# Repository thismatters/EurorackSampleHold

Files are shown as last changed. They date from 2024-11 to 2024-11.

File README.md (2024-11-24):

# Noise / Sample Hold

This module both generates random noise (white and pink) which can be used as an audio signal directly, or slow moving random voltages appropriate to use a CV. Additionally, it can sample that random noise and hold a CV (slash V/Oct). Module has an internal clock to control sample rate, which can be overridden.

The circuit here is based on the [Yusynth Random Module](https://yusynth.net/Modular/EN/NOISE/index.html) with minor tweaks to make it more Eurorack friendly. The changes I've made are thus:
* Selected resistors appropriate for +/-12V rails,
* Added polarity protection so that a backward power header doesn't fry anything (twin series schotty diodes: BAT54SL),
* Full surface mount design.

The Yusynth page is a treasure trove of information about this circuit that I am too amateur to claim as my own; please read that outstanding page before using this circuit. The page provides many details and other implementations of this circuit that you may find suitable.

The KiCAD project here uses the library/footprints [found in my companion repo](https://github.com/thismatters/EurorackKiCAD).

## Width

13hp on an Intellijel 1U rack.

## Inputs

Jacks for:
- Signal to be sampled,
- Gate controlling when sample is taken.

Switch for selecting between noise:
- White,
- Pink,
- Slow moving random voltage.

Knob for setting internal clock for sample rate.

## Outputs

Jacks for:
- Selected noise,
- Clock,
- Held voltage.

## Adjustment

Build this module using a socket for the discrete transistor. Try several transistors until you get a good spectrum of both white and pink noise.

## Vendors

There are part numbers in the [BOM](.csv) for many of the parts (not for basic passives though) at the following vendors:

* [Mouser](https://www.mouser.com): Needs no introduction. Get your ICs from here (or [digikey](https://www.digikey.com)).
* [Tayda Electronics](https://www.taydaelectronics.com/): Good supplier for passive components; audio jacks, and potentiometers. Their audio jacks are slightly smaller than the thonkiconn from thonk.
* [Love My Switches](https://lovemyswitches.com/): Has [really good knobs](https://lovemyswitches.com/anodized-aluminum-knob-the-lo-fi-1-4-smooth-shaft-12-5mm-od/) to go on those potentiometers!
* [OSHPark](https://oshpark.com/): Fast and (relatively) cheap PCB manufacturer. The [V0 circuit](https://oshpark.com/shared_projects/IxCpIOaM) works great!

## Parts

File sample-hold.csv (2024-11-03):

# | Reference | Qty | Value | Footprint | DNP | Vendor | PartNum
1 | C1, C2, C3, C4 | 4 | 22u 50V | Capacitor_THT:CP_Radial_D5.0mm_P2.50mm
2 | C5, C6 | 2 | 47u 50V | Capacitor_THT:CP_Radial_D6.3mm_P2.50mm
3 | C7, C18 | 2 | 100n | Capacitor_SMD:C_0805_2012Metric
4 | C8, C13, C21 | 3 | 10u 35V | Capacitor_THT:CP_Radial_D5.0mm_P2.50mm
5 | C9, C14 | 2 | 10p | Capacitor_SMD:C_0805_2012Metric
6 | C10 | 1 | 47n box | Capacitor_THT:C_Rect_L7.2mm_W2.5mm_P5.00mm_FKS2_FKP2_MKS2_MKP2
7 | C11 | 1 | 1n box | Capacitor_THT:C_Rect_L7.2mm_W2.5mm_P5.00mm_FKS2_FKP2_MKS2_MKP2
8 | C12 | 1 | 3.3n box | Capacitor_THT:C_Rect_L7.2mm_W2.5mm_P5.00mm_FKS2_FKP2_MKS2_MKP2
9 | C15, C16 | 2 | 1u box | Capacitor_THT:C_Rect_L7.2mm_W5.5mm_P5.00mm_FKS2_FKP2_MKS2_MKP2
10 | C17 | 1 | 150n box | Capacitor_THT:C_Rect_L7.2mm_W3.5mm_P5.00mm_FKS2_FKP2_MKS2_MKP2
11 | C19 | 1 | 1n | Capacitor_SMD:C_0805_2012Metric
12 | C20 | 1 | 100n box | Capacitor_THT:C_Rect_L7.2mm_W2.5mm_P5.00mm_FKS2_FKP2_MKS2_MKP2
13 | D1, D2 | 2 | BAT54S | Package_TO_SOT_SMD:SOT-23 |  | Mouser | 863-BAT54SLT1G
14 | D3, D4, D5 | 3 | 1N4148 | Diode_SMD:D_SOD-323_HandSoldering
15 | J1 | 1 | Conn_02x05_Odd_Even | Eurorack:PinHeader_2x05_P2.54mm_Vertical |  | Tayda | A-2939
16 | J2, J3, J4, J5, J6 | 5 | AudioJack2_SwitchT | Eurorack:AudioJack2_Tayda_A-2566 |  | Tayda | A-2566
17 | J7, J9, J11 | 3 | Conn_01x03_Pin | Connector_PinHeader_2.54mm:PinHeader_1x03_P2.54mm_Vertical
18 | J8, J10, J12 | 3 | Conn_01x03_Socket | Connector_PinSocket_2.54mm:PinSocket_1x03_P2.54mm_Vertical
19 | Q1 | 1 | BC547C | Package_TO_SOT_THT:TO-92_Inline_Wide |  | Mouser | 637-BC547C
20 | Q2 | 1 | BCM847 | Package_SO:TSOP-6_1.65x3.05mm_P0.95mm |  | Mouser | 771-BCM847DS135
21 | Q3 | 1 | MMBFJ111 | Package_TO_SOT_SMD:SOT-23 |  | Mouser | 863-MMBF4393LT1G
22 | R1, R2, R3, R4 | 4 | 10 | Resistor_SMD:R_0805_2012Metric
23 | R5 | 1 | 47K | Resistor_SMD:R_0805_2012Metric
24 | R6 | 1 | 150K | Resistor_SMD:R_0805_2012Metric
25 | R7, R22, R28 | 3 | 10K | Resistor_SMD:R_0805_2012Metric
26 | R8 | 1 | 22 | Resistor_SMD:R_0805_2012Metric
27 | R9, R20, R21, R43 | 4 | 33K | Resistor_SMD:R_0805_2012Metric
28 | R10, R18 | 2 | 470K | Resistor_SMD:R_0805_2012Metric
29 | R11, R19, R24, R25, R32, R36 | 6 | 1K | Resistor_SMD:R_0805_2012Metric
30 | R12 | 1 | 82K | Resistor_SMD:R_0805_2012Metric
31 | R13, R26, R27, R29, R30, R34, R37, R38, R39, R40 | 10 | 100K | Resistor_SMD:R_0805_2012Metric
32 | R14 | 1 | 18K | Resistor_SMD:R_0805_2012Metric
33 | R15 | 1 | 390K | Resistor_SMD:R_0805_2012Metric
34 | R16 | 1 | 1M | Resistor_SMD:R_0805_2012Metric
35 | R17 | 1 | 8.2K | Resistor_SMD:R_0805_2012Metric
36 | R23 | 1 | 220K | Resistor_SMD:R_0805_2012Metric
37 | R31 | 1 | 2.2M | Resistor_SMD:R_0805_2012Metric
38 | R33 | 1 | 2.2K | Resistor_SMD:R_0805_2012Metric
39 | R35 | 1 | 120K | Resistor_SMD:R_0805_2012Metric
40 | R41 | 1 | 3.9K | Resistor_SMD:R_0805_2012Metric
41 | R42 | 1 | 24K | Resistor_SMD:R_0805_2012Metric
42 | RV1 | 1 | C500K | Eurorack:Potentiometer_RV16AF-41-15R1 |  | Tayda | A-3940
43 | SW1 | 1 | ON-ON-ON | Eurorack:Switch_DPDT_Tayda_A-5752 |  | Tayda | A-6677
44 | U1, U2 | 2 | TL074 | Package_SO:SOIC-14_3.9x8.7mm_P1.27mm |  | Mouser | 595-TL074CDR

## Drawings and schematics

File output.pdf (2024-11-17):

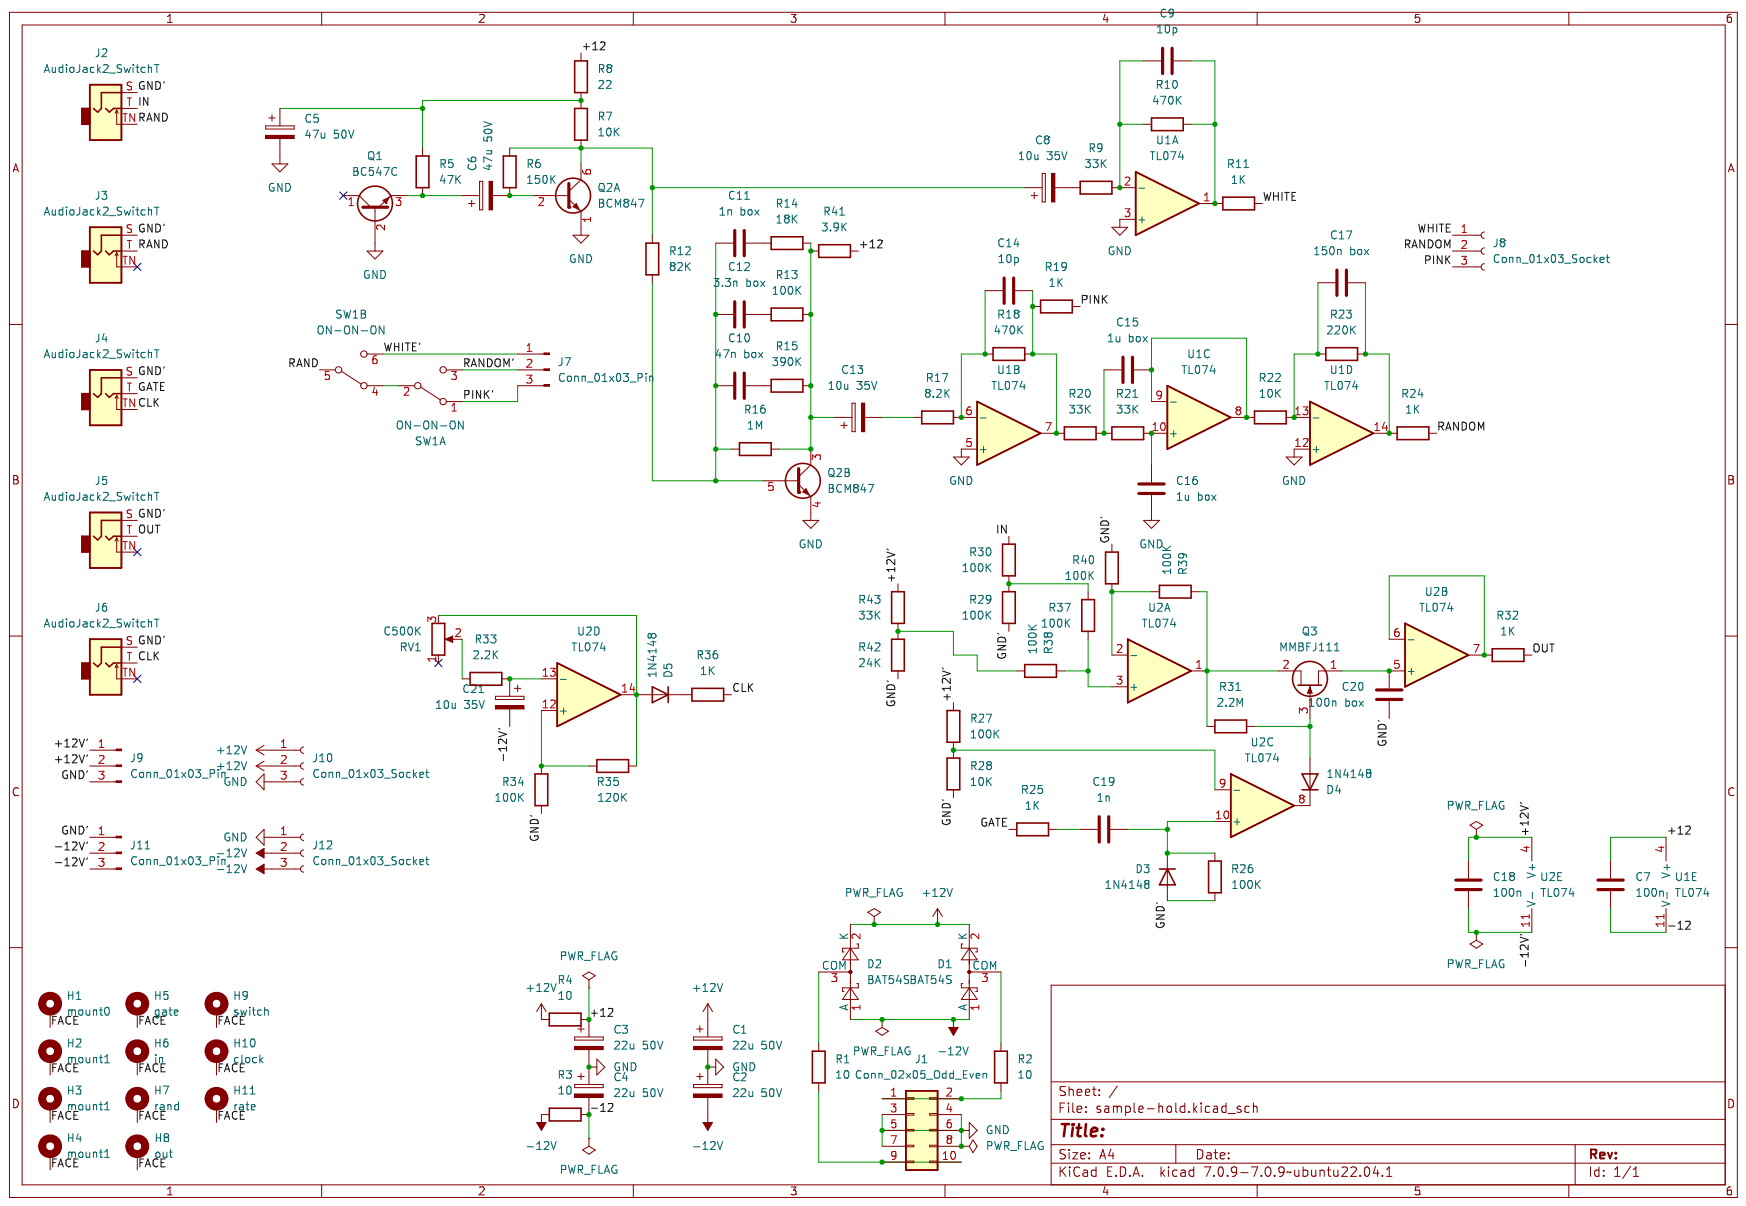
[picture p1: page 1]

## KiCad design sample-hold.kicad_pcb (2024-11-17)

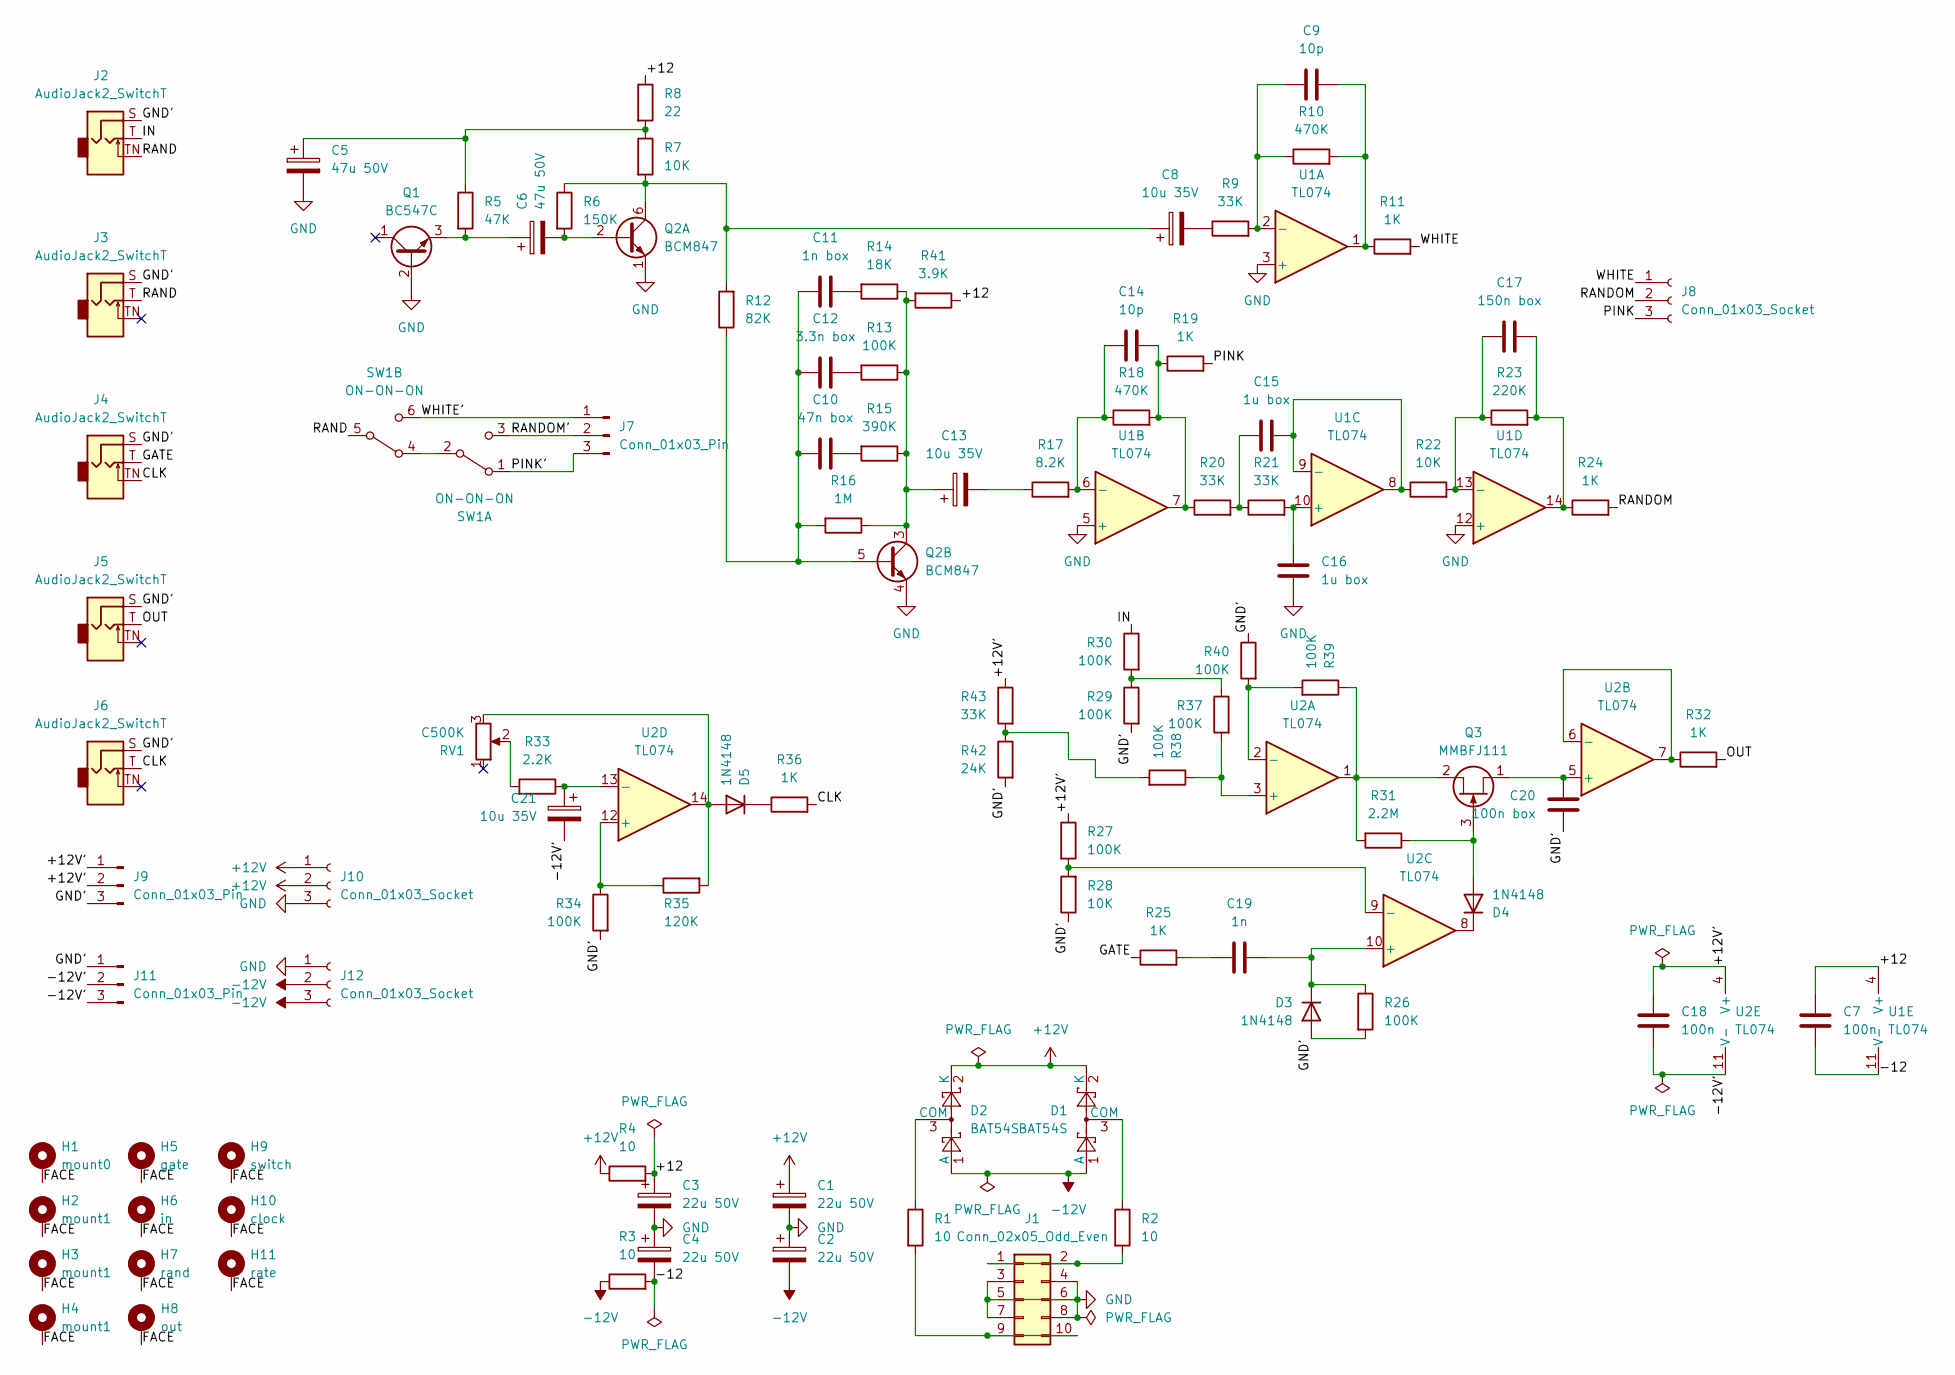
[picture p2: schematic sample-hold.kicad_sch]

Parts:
C1, C2, C3, C4: 22u 50V; CP_Radial_D5.0mm_P2.50mm
C5, C6: 47u 50V; CP_Radial_D6.3mm_P2.50mm
C7, C18: 100n; C_0805_2012Metric
C8, C13, C21: 10u 35V; CP_Radial_D5.0mm_P2.50mm
C9, C14: 10p; C_0805_2012Metric
C10: 47n box; C_Rect_L7.2mm_W2.5mm_P5.00mm_FKS2_FKP2_MKS2_MKP2
C11: 1n box; C_Rect_L7.2mm_W2.5mm_P5.00mm_FKS2_FKP2_MKS2_MKP2
C12: 3.3n box; C_Rect_L7.2mm_W2.5mm_P5.00mm_FKS2_FKP2_MKS2_MKP2
C15, C16: 1u box; C_Rect_L7.2mm_W5.5mm_P5.00mm_FKS2_FKP2_MKS2_MKP2
C17: 150n box; C_Rect_L7.2mm_W3.5mm_P5.00mm_FKS2_FKP2_MKS2_MKP2
C19: 1n; C_0805_2012Metric
C20: 100n box; C_Rect_L7.2mm_W2.5mm_P5.00mm_FKS2_FKP2_MKS2_MKP2
D1, D2: BAT54S; SOT-23; PartNum 863-BAT54SLT1G
D3, D4, D5: 1N4148; D_SOD-323_HandSoldering
H1: mount0; Mech-MountingHole
H2, H3, H4: mount1; Mech-MountingHole
H5: gate; Mech-AudioJack-Hole-Input-Gate
H6: in; Mech-AudioJack-Hole-Input-Voct
H7: rand; Mech-AudioJack-Hole-Output-Voct
H8: out; Mech-AudioJack-Hole-Output-Voct
H9: switch; Mech-2M_Switch-Hole
H10: clock; Mech-AudioJack-Hole-Output-Clock
H11: rate; Mech-Potentiometer-Hole_level_90deg
J1: Conn_02x05_Odd_Even; PinHeader_2x05_P2.54mm_Vertical; PartNum A-2939
J2, J3, J4, J5, J6: AudioJack2_SwitchT; AudioJack2_Tayda_A-2566; PartNum A-2566
J7, J9, J11: Conn_01x03_Pin; PinHeader_1x03_P2.54mm_Vertical
J8, J10, J12: Conn_01x03_Socket; PinSocket_1x03_P2.54mm_Vertical
Q1: BC547C; TO-92_Inline_Wide; PartNum 637-BC547C
Q2: BCM847; TSOP-6_1.65x3.05mm_P0.95mm; PartNum 771-BCM847DS135
Q3: MMBFJ111; SOT-23; PartNum 863-MMBF4393LT1G
R1, R2, R3, R4: 10; R_0805_2012Metric
R5: 47K; R_0805_2012Metric
R6: 150K; R_0805_2012Metric
R7, R22, R28: 10K; R_0805_2012Metric
R8: 22; R_0805_2012Metric
R9, R20, R21, R43: 33K; R_0805_2012Metric
R10, R18: 470K; R_0805_2012Metric
R11, R19, R24, R25, R32, R36: 1K; R_0805_2012Metric
R12: 82K; R_0805_2012Metric
R13, R26, R27, R29, R30, R34, R37, R38, R39, R40: 100K; R_0805_2012Metric
R14: 18K; R_0805_2012Metric
R15: 390K; R_0805_2012Metric
R16: 1M; R_0805_2012Metric
R17: 8.2K; R_0805_2012Metric
R23: 220K; R_0805_2012Metric
R31: 2.2M; R_0805_2012Metric
R33: 2.2K; R_0805_2012Metric
R35: 120K; R_0805_2012Metric
R41: 3.9K; R_0805_2012Metric
R42: 24K; R_0805_2012Metric
RV1: C500K; Potentiometer_RV16AF-41-15R1; PartNum A-3940
SW1: ON-ON-ON; Switch_DPDT_Tayda_A-5752; PartNum A-6677
U1, U2: TL074; SOIC-14_3.9x8.7mm_P1.27mm; PartNum 595-TL074CDR

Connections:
+12V: C1.1, D1.2 (K), D2.2 (K), J10.1, J10.2, R4.1
-12V: C2.2, D1.1 (A), D2.1 (A), J12.2, J12.3, R3.1
/+12: C3.1, C7.1, R4.2, R8.1, R41.1, U1.4 (V+)
/+12V': C18.1, J9.1, J9.2, R27.1, R43.1, U2.4 (V+)
/-12: C4.2, C7.2, R3.2, U1.11 (V-)
/-12V': C18.2, C21.2, J11.2, J11.3, U2.11 (V-)
/CLK: J4.TN, J6.T, R36.2
/FACE: H1.1, H2.1, H3.1, H4.1, H5.1, H6.1, H7.1, H8.1, H9.1, H10.1, H11.1
/GATE: J4.T, R25.1
/GND': C20.2, D3.2 (A), J2.S, J3.S, J4.S, J5.S, J6.S, J9.3, J11.1, R26.2, R28.1, R29.2, R34.2, R40.1, R42.2
/IN: J2.T, R30.1
/OUT: J5.T, R32.2
/PINK: J8.3, R19.2
/PINK': J7.3, SW1.1 (A)
/RAND: J2.TN, J3.T, SW1.5 (B)
/RANDOM: J8.2, R24.2
/RANDOM': J7.2, SW1.3 (C)
/WHITE: J8.1, R11.2
/WHITE': J7.1, SW1.6 (C)
GND: C1.2, C2.1, C3.2, C4.1, C5.2, C16.1, J1.3, J1.4, J1.5, J1.6, J1.7, J1.8, J10.3, J12.1, Q1.2 (B), Q2.1 (E1), Q2.4 (E2), U1.3 (+), U1.5 (+), U1.12 (+)
unnamed: C5.1, R5.1, R7.1, R8.2
unnamed: C8.2, R9.1
unnamed: C9.2, R10.2, R11.1, U1.1
unnamed: C10.2, R15.2
unnamed: C11.2, R14.2
unnamed: C12.2, R13.2
unnamed: C13.2, R17.1
unnamed: C14.2, R18.2, R19.1, R20.1, U1.7
unnamed: C15.1, R20.2, R21.1
unnamed: C17.2, R23.2, R24.1, U1.14
unnamed: C19.1, R25.2
unnamed: D1.3 (COM), R2.1
unnamed: D2.3 (COM), R1.1
unnamed: C19.2, D3.1 (K), R26.1, U2.10 (+)
unnamed: D4.2 (A), Q3.3 (G), R31.1
unnamed: D4.1 (K), U2.8
unnamed: D5.2 (A), R35.2, RV1.3, U2.14
unnamed: D5.1 (K), R36.1
unnamed: J1.1, J1.2, R2.2
unnamed: J1.9, J1.10, R1.2
unnamed: C6.1, Q1.3 (E), R5.2
unnamed: C6.2, Q2.2 (B1), R6.2
unnamed: C8.1, Q2.6 (C1), R6.1, R7.2, R12.2
unnamed: C10.1, C11.1, C12.1, Q2.5 (B2), R12.1, R16.2
unnamed: C13.1, Q2.3 (C2), R13.1, R14.1, R15.1, R16.1, R41.2
unnamed: C20.1, Q3.1 (D), U2.5 (+)
unnamed: Q3.2 (S), R31.2, R39.1, U2.1
unnamed: R29.1, R30.2, R37.1
unnamed: R33.2, RV1.2
unnamed: R38.2, R42.1, R43.2
unnamed: SW1.2 (B), SW1.4 (A)
unnamed: C9.1, R9.2, R10.1, U1.2 (-)
unnamed: C14.1, R17.2, R18.1, U1.6 (-)
unnamed: C16.2, R21.2, U1.10 (+)
unnamed: C15.2, R22.1, U1.8, U1.9 (-)
unnamed: C17.1, R22.2, R23.1, U1.13 (-)
unnamed: R37.2, R38.1, U2.3 (+)
unnamed: R39.2, R40.2, U2.2 (-)
unnamed: R32.1, U2.6 (-), U2.7
unnamed: R27.2, R28.2, U2.9 (-)
unnamed: R34.1, R35.1, U2.12 (+)
unnamed: C21.1, R33.1, U2.13 (-)

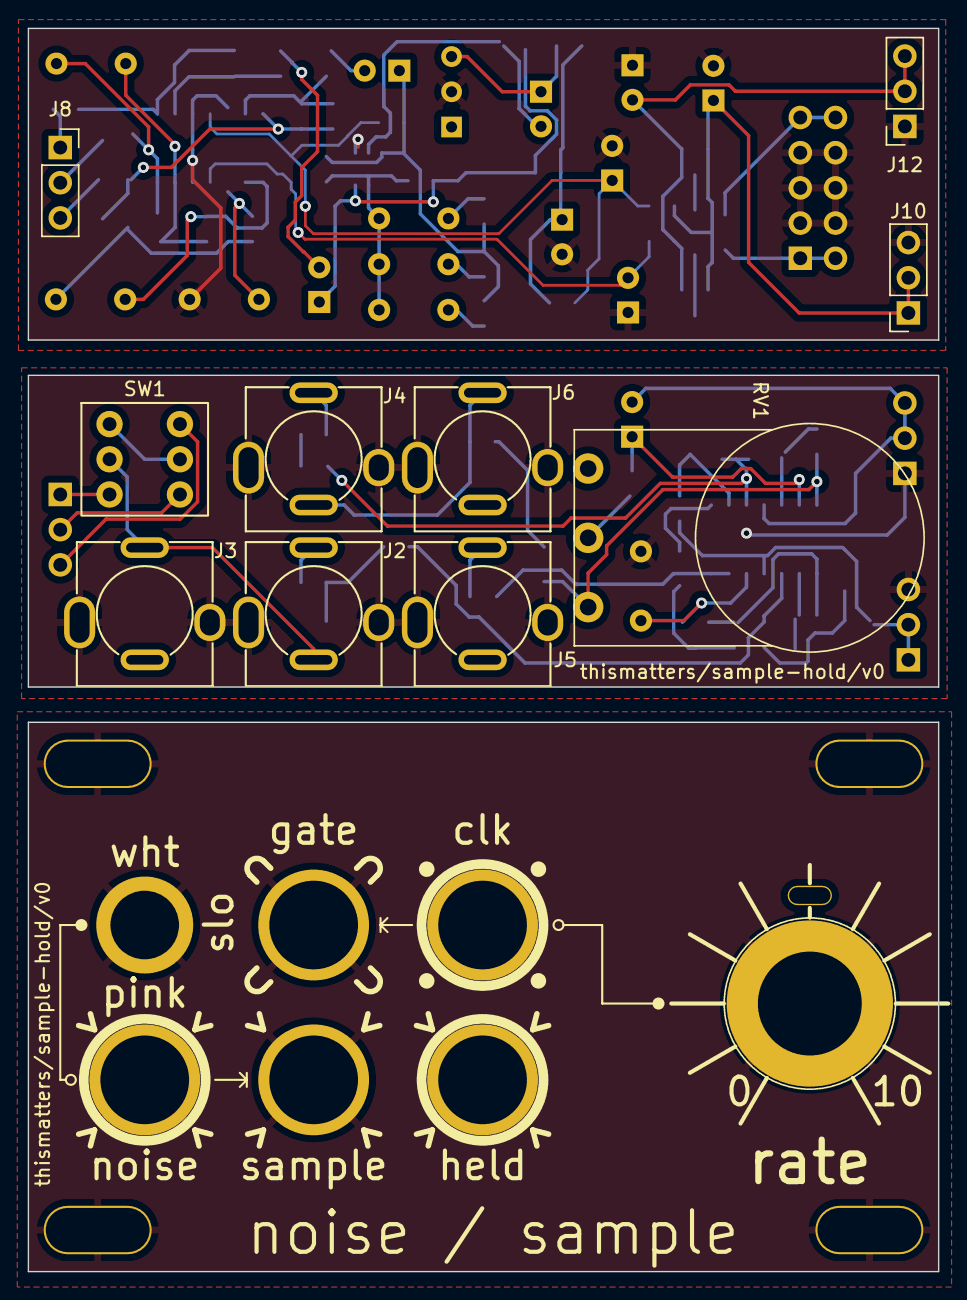
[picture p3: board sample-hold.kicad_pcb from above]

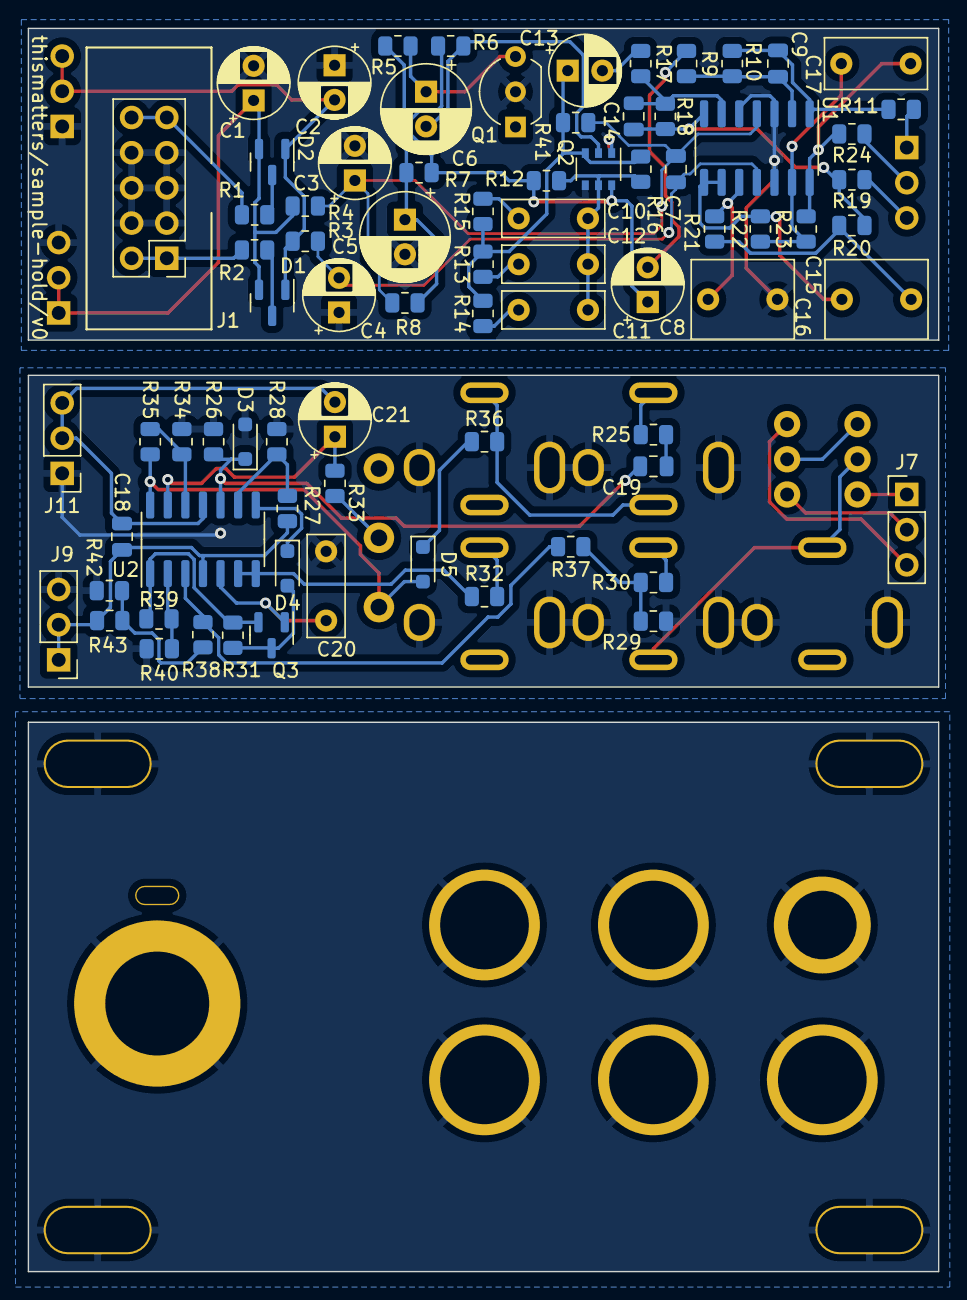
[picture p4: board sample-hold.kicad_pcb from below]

Board: 2 copper layers, 65.7 x 89.7 mm, 99 parts (78 on the bottom side), 62 nets.

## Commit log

2024-09-08 adding rate knob and internal clock
    [sample-hold.csv, sample-hold.kicad_pcb, sample-hold.kicad_sch]
2024-09-08 correct capacitor type
    [sample-hold.csv, sample-hold.kicad_pcb, sample-hold.kicad_sch]
2024-09-08 little routing cleanup
    [sample-hold.kicad_pcb]
2024-11-03 prototype tested and updates made ready for v0 manu
    [sample-hold.csv, sample-hold.kicad_pcb, sample-hold.kicad_sch]
2024-11-17 sent out for manu
    [sample-hold.kicad_pcb]
2024-11-24 adding circuit link
